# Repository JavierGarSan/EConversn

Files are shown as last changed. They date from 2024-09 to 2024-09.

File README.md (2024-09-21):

# EConversn
An open-source project that allows adapting a pre-existing bike into an ebike with throttle control using minimal components

# Goals 
Extend the range of people within an urban environment.
Allow faster transportation while hurting the environment less.
Make bikes more accessible by crafting a more affordable one.

# Missing
Spur gear with 10 teeth.

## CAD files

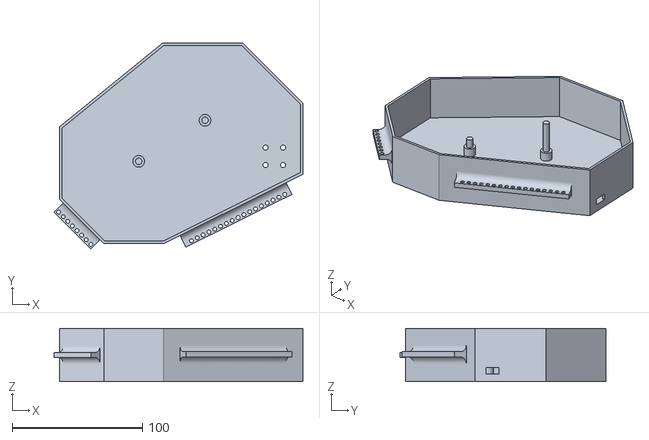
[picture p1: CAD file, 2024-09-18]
3D Models/Base of gearbox.obj
191.1 x 158.1 x 41.0

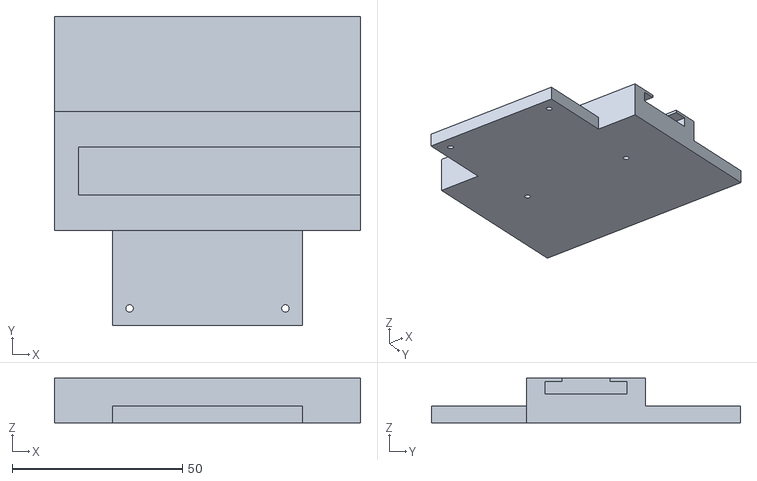
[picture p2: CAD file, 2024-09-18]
3D Models/ESC & Motherboard base plate.obj
90.0 x 91.0 x 13.1

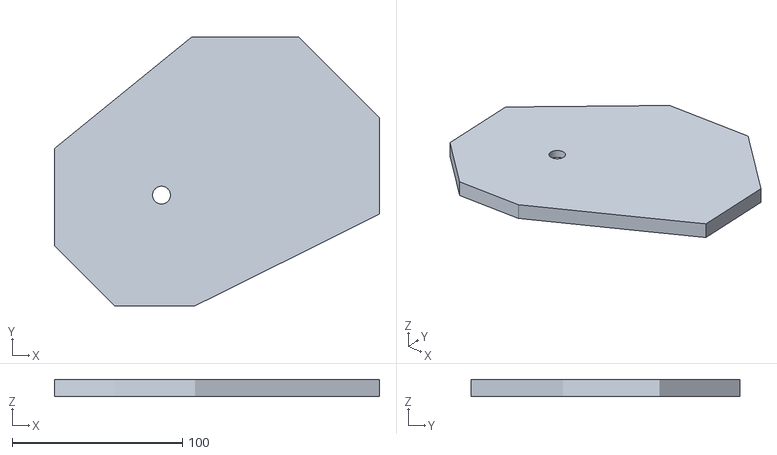
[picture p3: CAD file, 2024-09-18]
3D Models/Lid of gearbox.obj
191.0 x 158.0 x 10.0

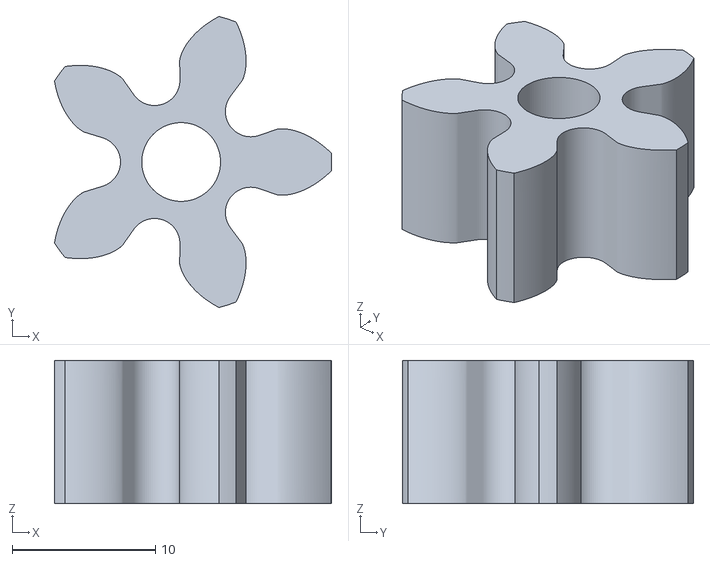
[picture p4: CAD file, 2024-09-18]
3D Models/Direct Input Gear 5 teeth.obj
19.3 x 20.3 x 10.0

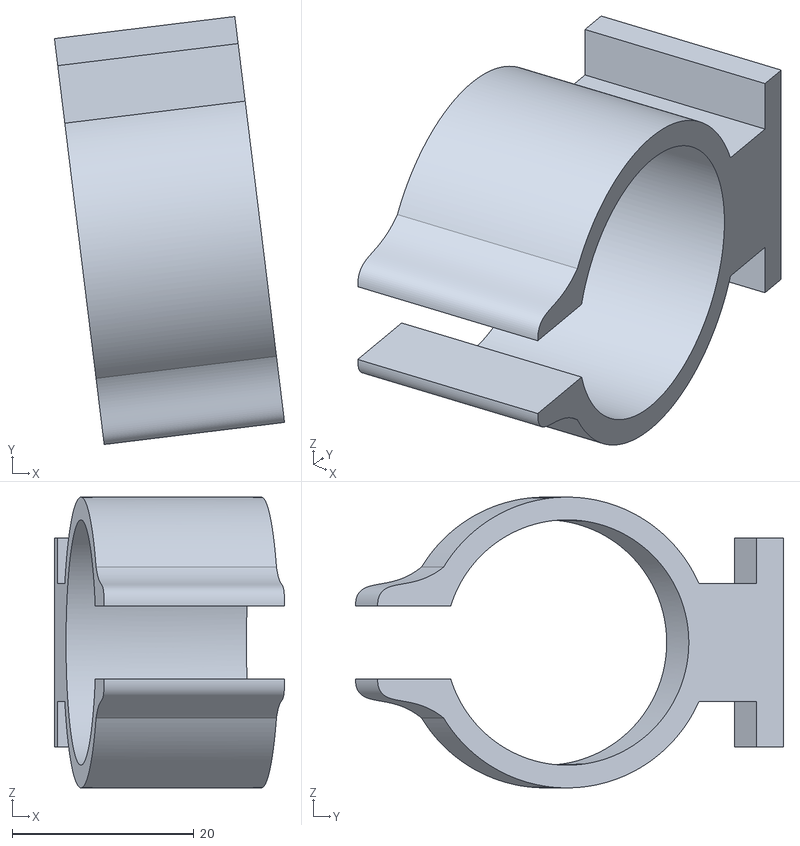
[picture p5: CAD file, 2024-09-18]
3D Models/ESC & Motherboard base plate holder.obj
25.3 x 47.1 x 32.0

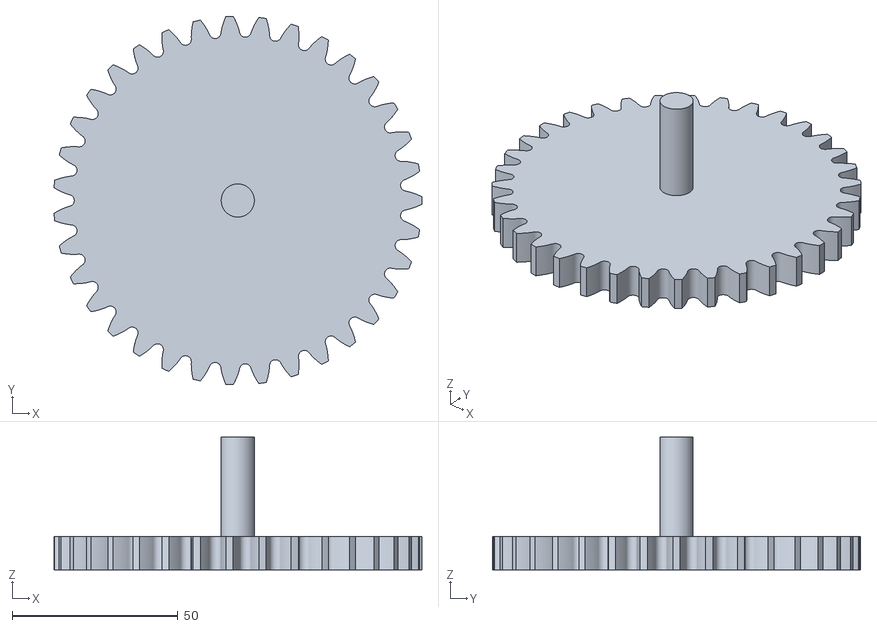
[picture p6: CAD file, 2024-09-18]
3D Models/Output Gear 35 Teeth.obj
110.9 x 111.0 x 40.0

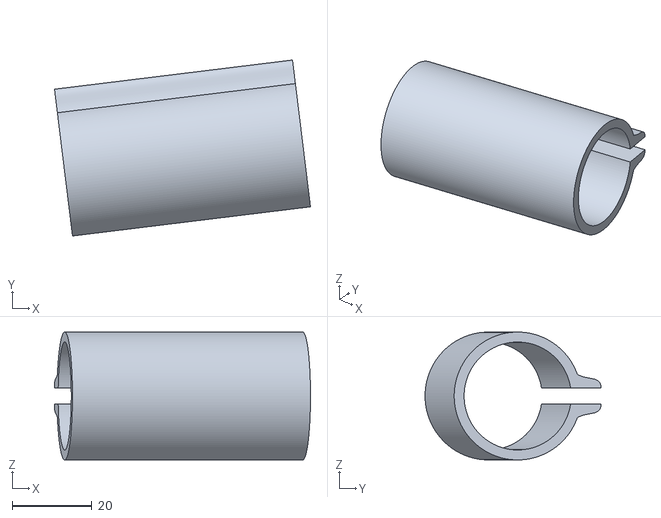
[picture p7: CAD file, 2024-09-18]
3D Models/Fishing line attachment.obj
64.1 x 44.0 x 32.0

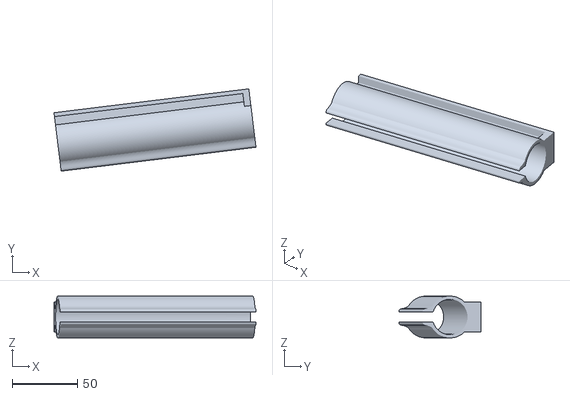
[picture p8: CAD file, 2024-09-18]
3D Models/Battery holder.obj
154.4 x 62.9 x 32.0

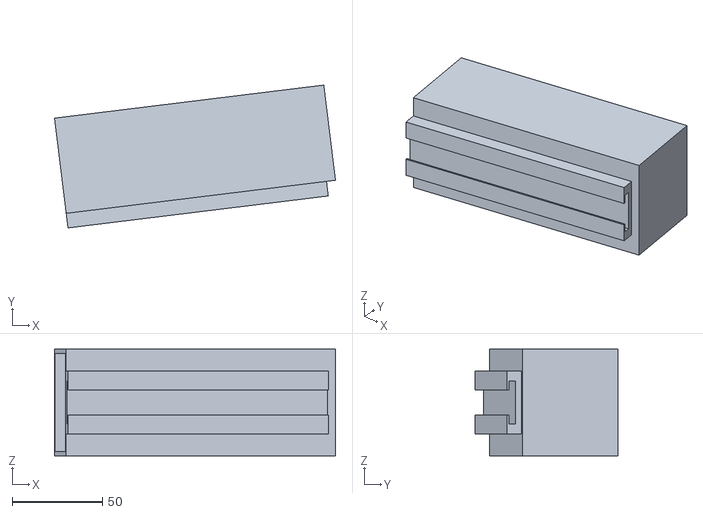
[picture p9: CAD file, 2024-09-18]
3D Models/Battery case.obj
155.3 x 79.0 x 59.0

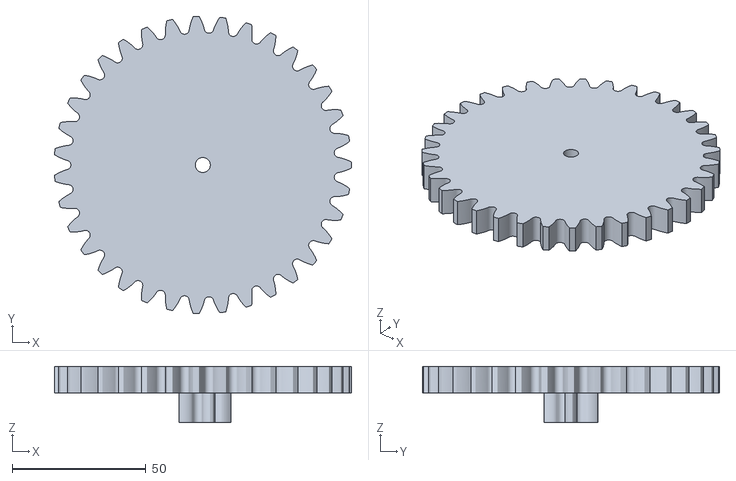
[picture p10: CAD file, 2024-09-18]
3D Models/Trabsitory gear 35 Teeth + 5 teeth.obj
110.9 x 111.0 x 21.0

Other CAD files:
3D Models/Small Sprocket 10 Teeth.obj

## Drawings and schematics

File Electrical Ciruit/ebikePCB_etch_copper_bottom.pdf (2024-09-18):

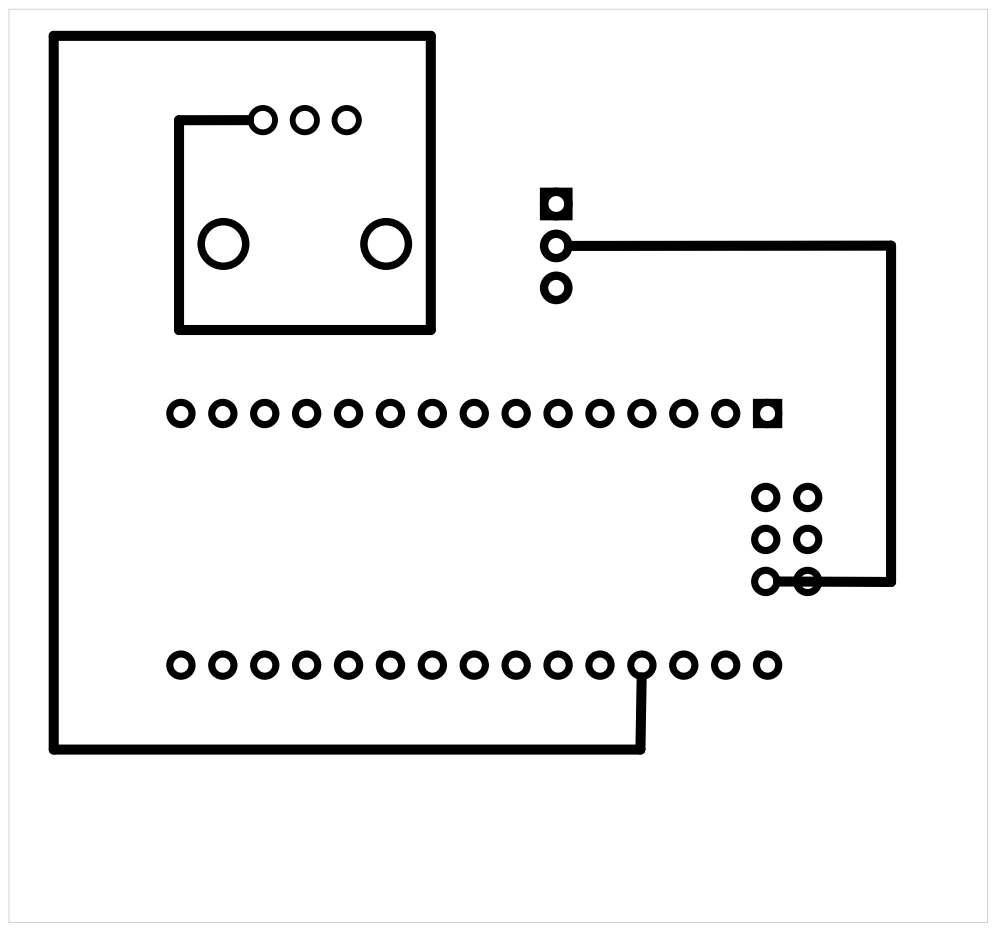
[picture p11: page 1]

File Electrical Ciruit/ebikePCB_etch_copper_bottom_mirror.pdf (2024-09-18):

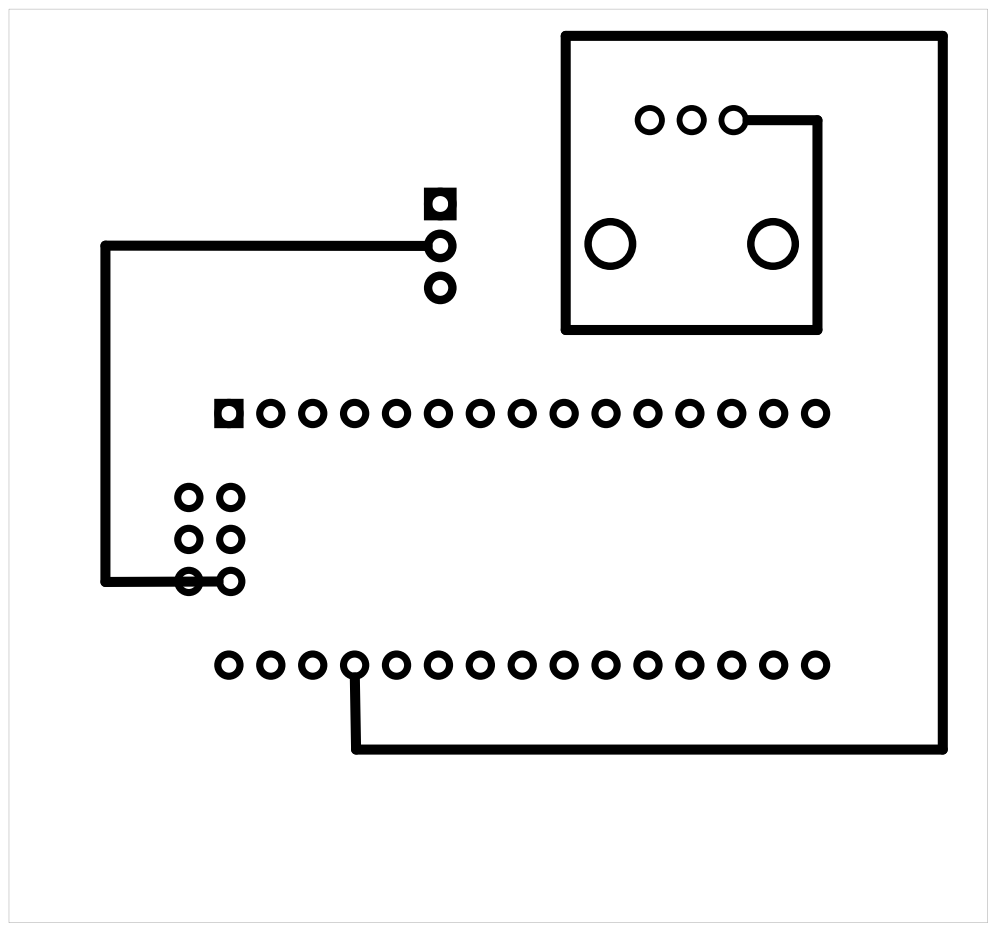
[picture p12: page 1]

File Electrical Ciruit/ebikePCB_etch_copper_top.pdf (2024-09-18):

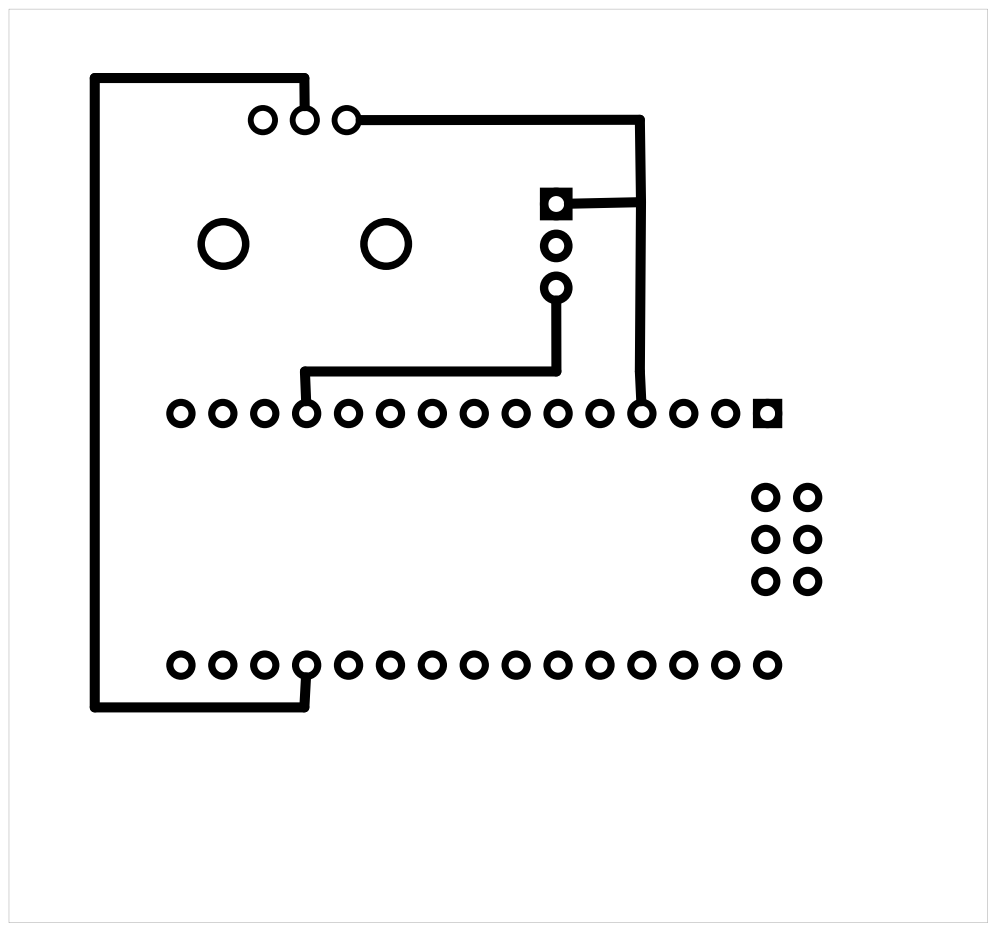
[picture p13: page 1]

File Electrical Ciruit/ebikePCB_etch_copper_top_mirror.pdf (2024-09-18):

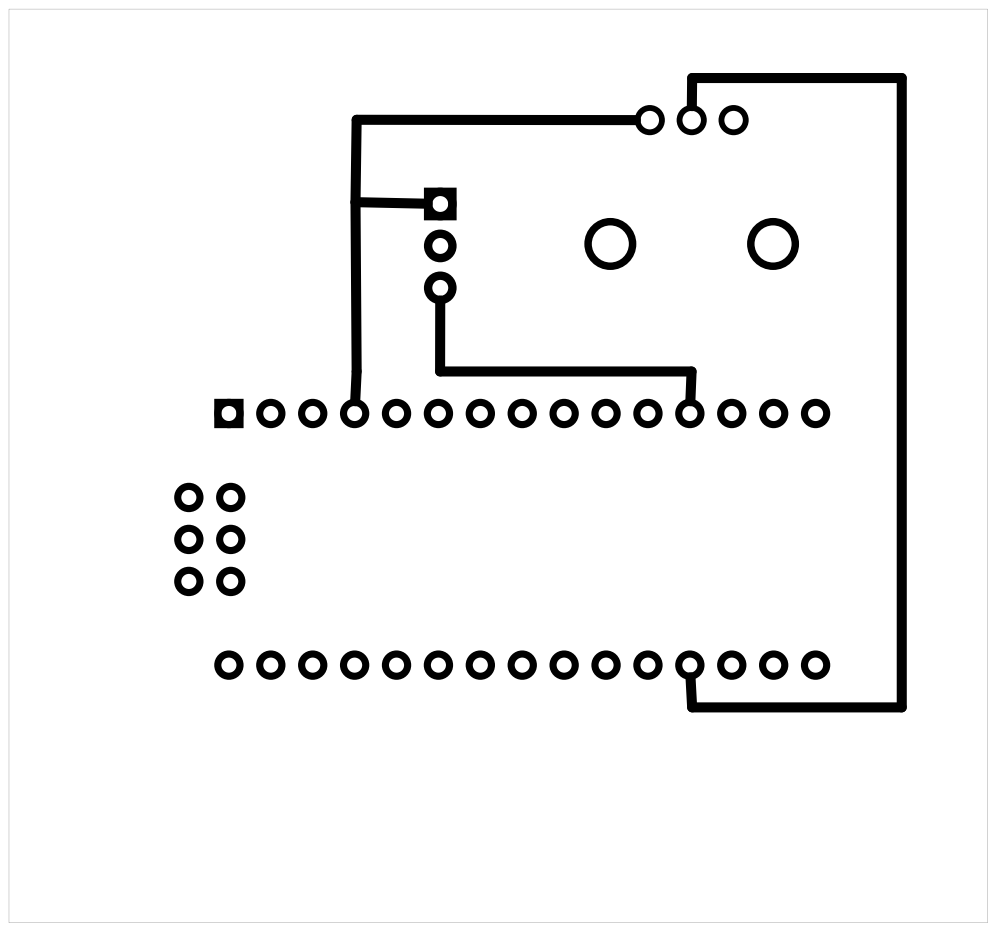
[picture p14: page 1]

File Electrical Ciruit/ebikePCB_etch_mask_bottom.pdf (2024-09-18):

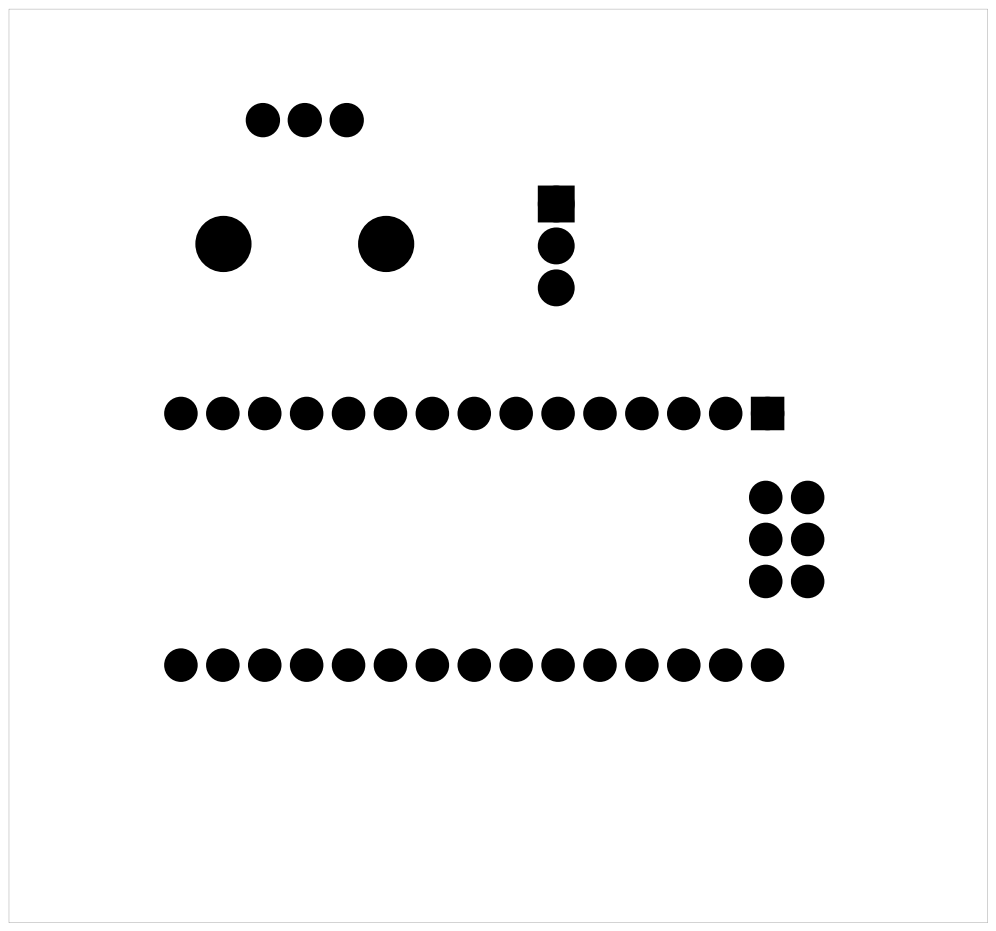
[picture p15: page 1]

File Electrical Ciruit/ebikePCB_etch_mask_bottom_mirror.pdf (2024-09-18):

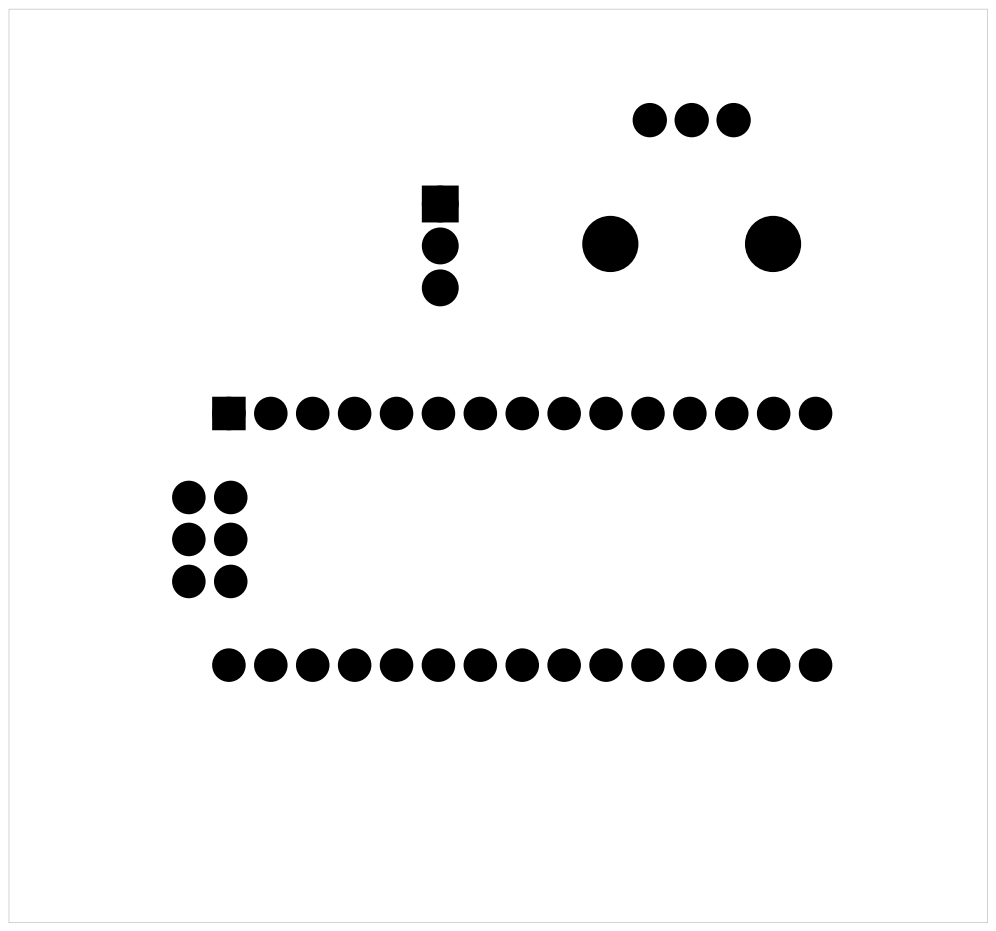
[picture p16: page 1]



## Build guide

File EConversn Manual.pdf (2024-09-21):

### Mathematics

Electric bikes usually have 250w -> 350w for leisurely drives
∴ we can use different power modes to conserve battery while still having a very high top speed which can be an extra benefit.

About 1000 W are wanted so we are going to use a 60A ESC and a 22.2V battery. (ESCs have an 80% power efficiency)
48A*22.2V = 1065.6 W

Torque can be calculated using the formula: T= (T is torque in Nm and P power in kV)

P*9550
RPM
RPM can be obtained using the kV of our motor, in this scenario it is 0.353 (0.35261538461)Nm
Yamaha’s Sport motor has 70Nm of torque and 300W of power. Bikes can go as low as 30 Nm. Gear ratios can be used to increase torque so we have to create a gear ratio of 1:98 (Two gears that convert it to 1:49 (1:7 each) and then chains 1:2).

### Parts

Motor (https://es.aliexpress.com/item/1005006350909209.html?scm_id=1007.40050.354490.0&scm-url=1007.40050.354490.0)
ESC (https://es.aliexpress.com/item/1005005479530832.html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)
Battery (https://es.aliexpress.com/item/1005003244765519.html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)
Arduino Nano (https://store.arduino.cc/en-es/products/arduino-nano)

### Gearbox + motor

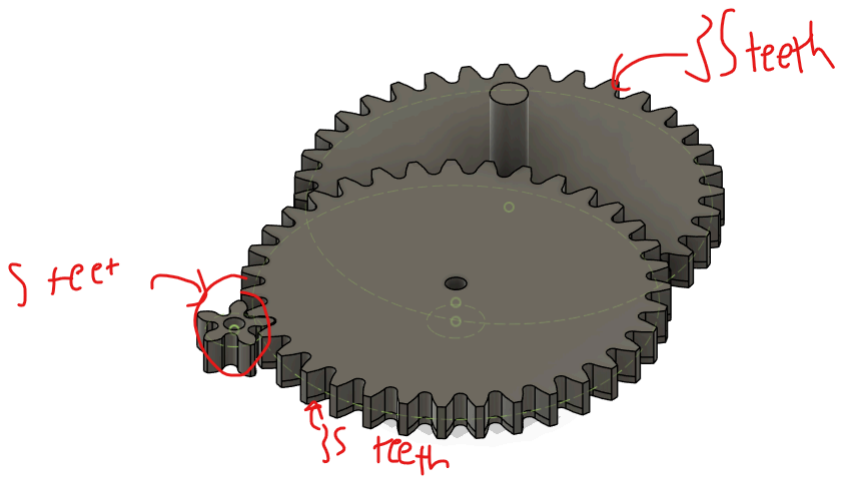
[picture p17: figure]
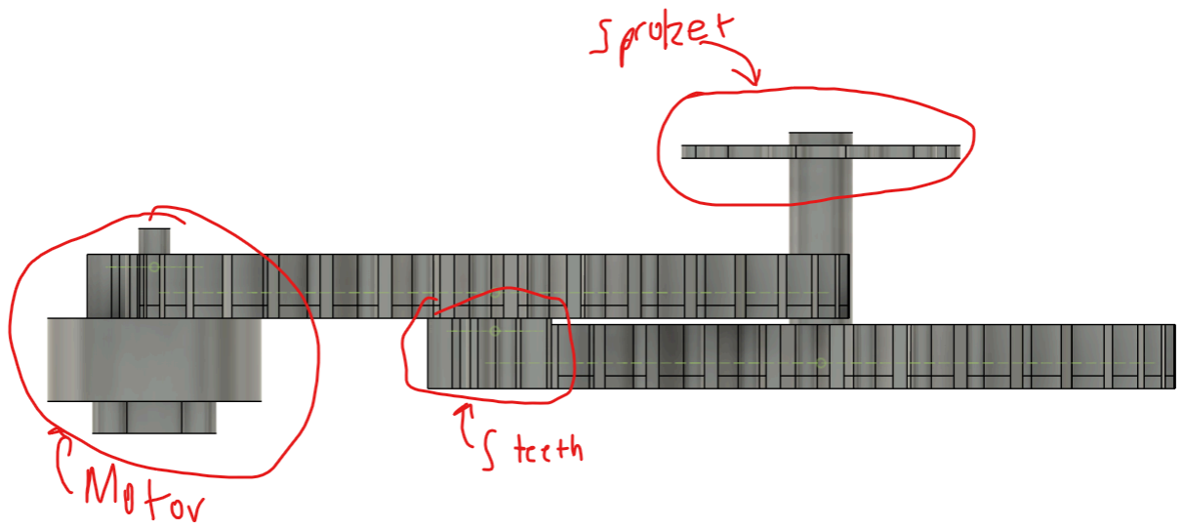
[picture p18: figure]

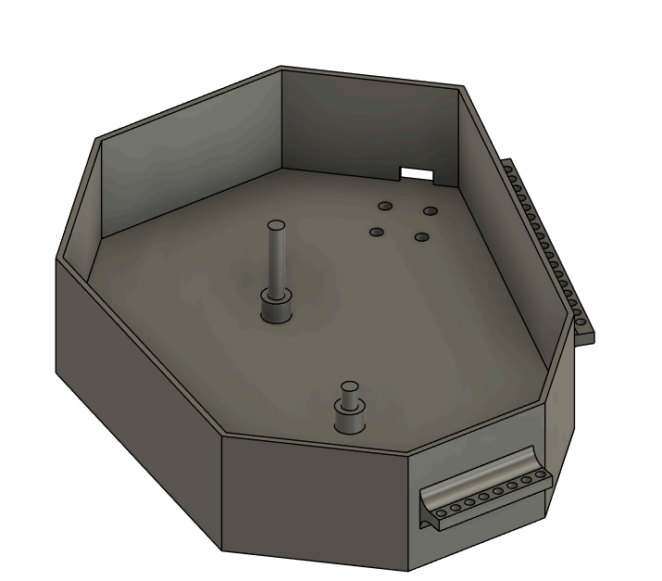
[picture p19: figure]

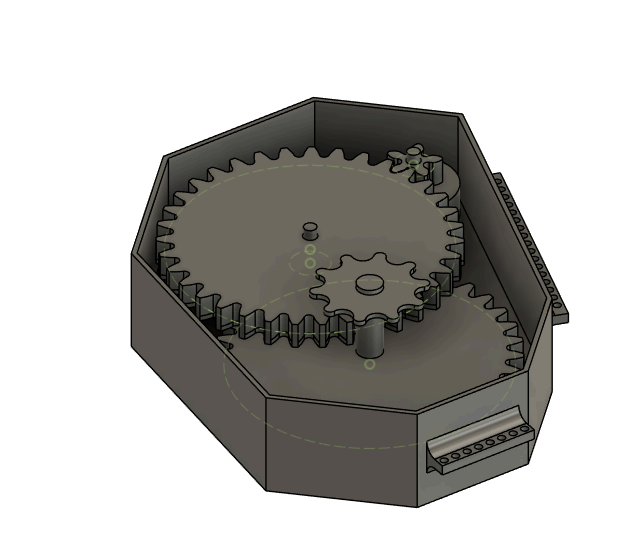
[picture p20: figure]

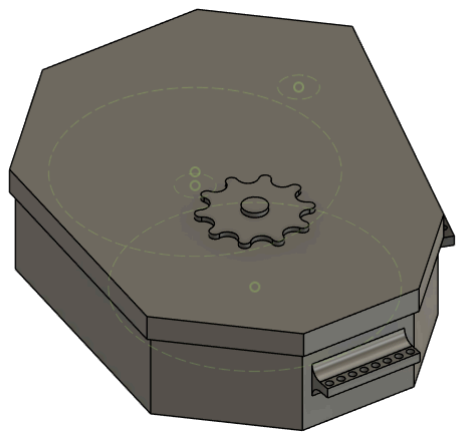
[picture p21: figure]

### Battery case

Holds batter (surprising). Weight could be reduced.

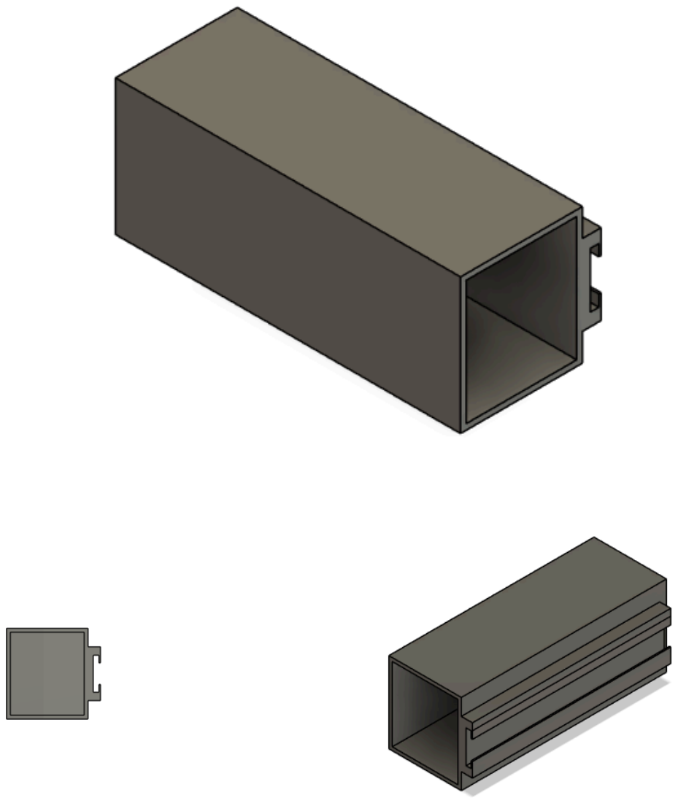
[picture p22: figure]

### PCB

The Ebike uses a simple custom PCB that holds an Arduino Nano and soldering holes for the potentiometer and the ESC connections. The PCB was designed using fritzing.

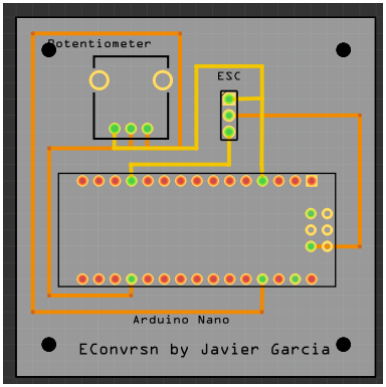
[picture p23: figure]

The arduino’s digital 9 port and analog 0 ports are being used.

### PCB + ESC Holder

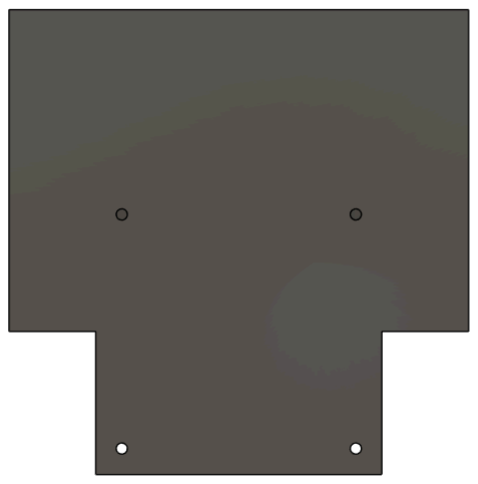
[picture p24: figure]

PCB is held by screws, ESC has no clear way fo being attached so it is clamped down by multiple ruber bands

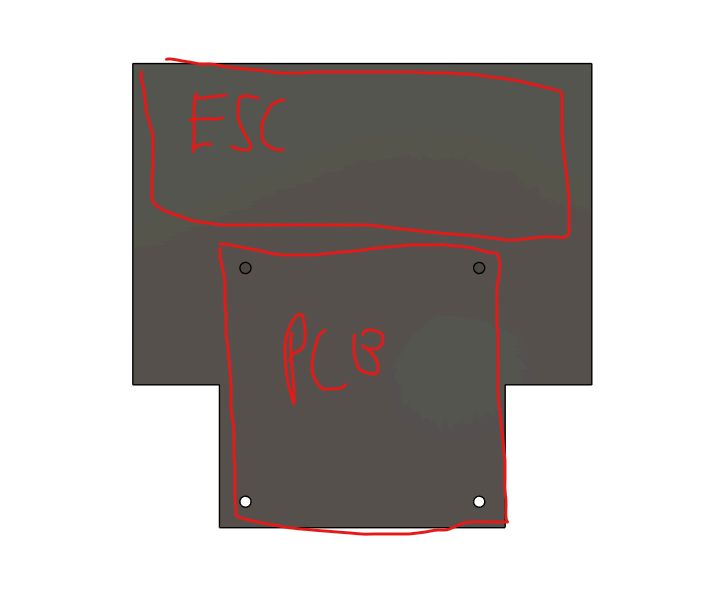
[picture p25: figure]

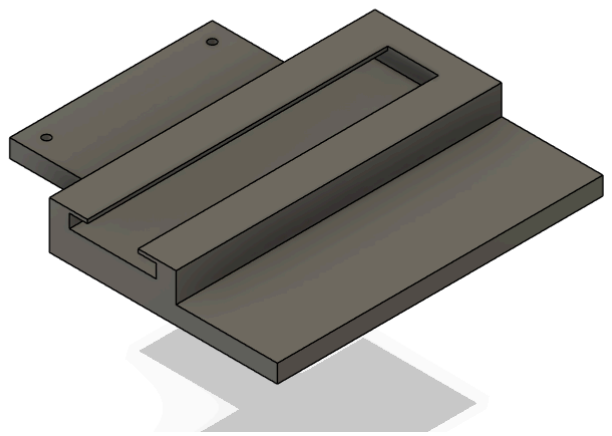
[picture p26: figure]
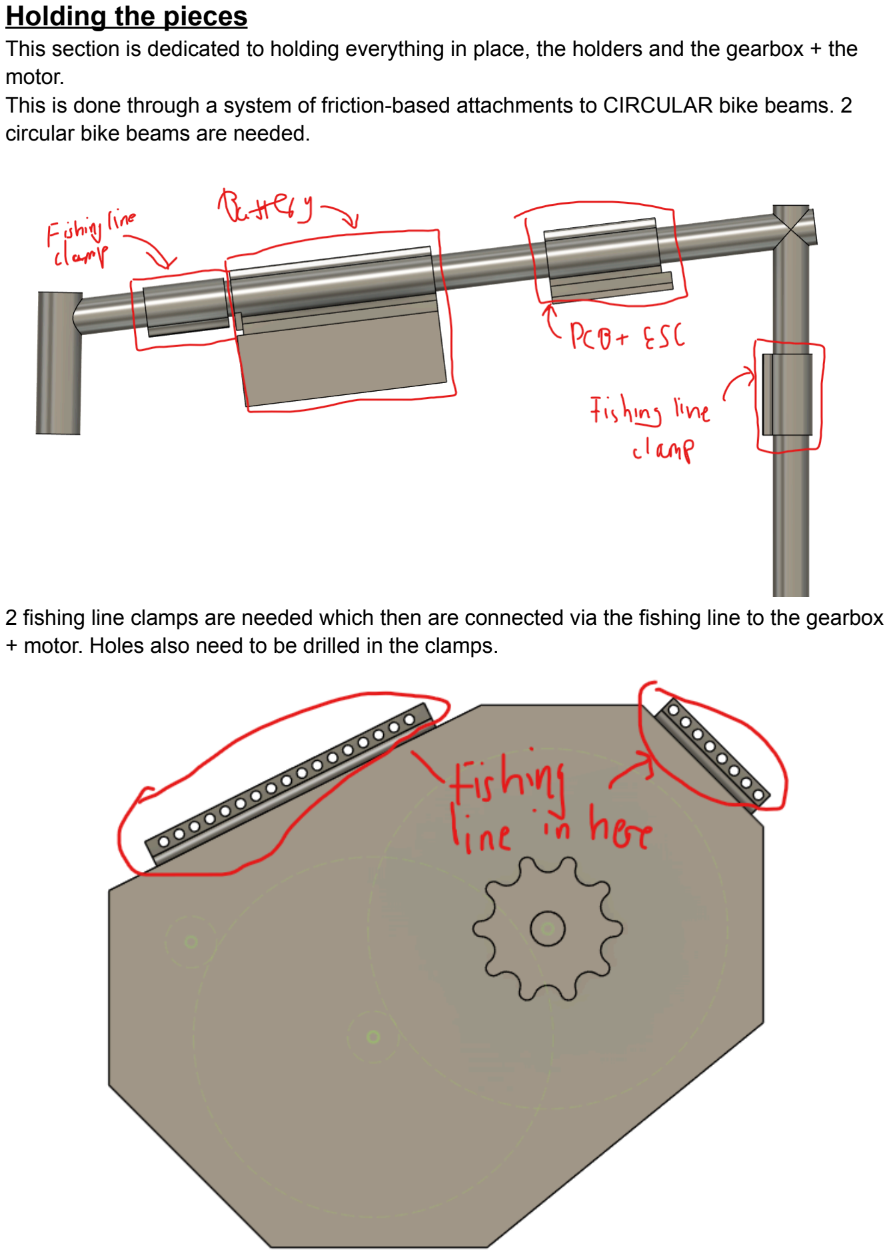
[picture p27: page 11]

### Holding the pieces

This section is dedicated to holding everything in place, the holders and the gearbox + the motor.
This is done through a system of friction-based attachments to CIRCULAR bike beams. 2 circular bike beams are needed.

2 fishing line clamps are needed which then are connected via the fishing line to the gearbox + motor. Holes also need to be drilled in the clamps.

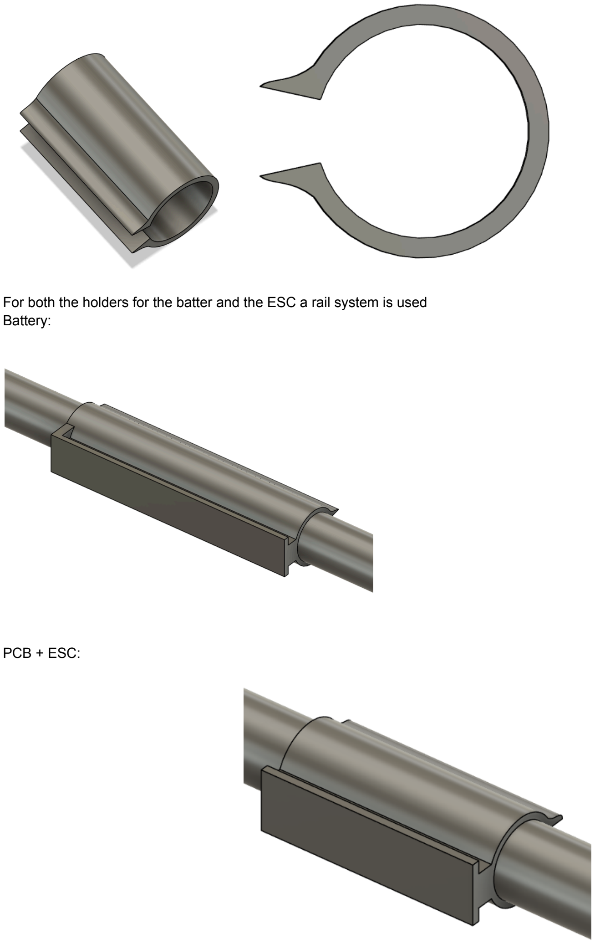
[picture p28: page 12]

For both the holders for the batter and the ESC a rail system is used Battery:

PCB + ESC:

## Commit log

2024-09-18 Commit added 3d models + modified README
    [Base of gearbox.obj, Battery case.obj, Battery holder.obj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]
2024-09-18 Added PCB
    [ebikePCB.fzz]
